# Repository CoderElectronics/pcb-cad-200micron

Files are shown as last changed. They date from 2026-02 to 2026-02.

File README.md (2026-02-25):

<div align="center">
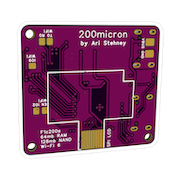
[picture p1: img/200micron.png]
200micron Setup Tool
  
  <h1>200micron SBC PCB/CAD</h1>
</div>

PCB/CAD for 200micron Linux Single-board computer. This is my attempt at designing a simple, low-cost and hand-assemble-able single-board computer for embedded robotics and UAV applications where a larger, more power-hungry system is not required. The board is completely single-sided and uses all SMD components >= 0402 size.

Best of all, it's open-source and comes with lots of resources and an SDK:
- [Custom Buildroot Tree w/ Cross SDK](https://github.com/CoderElectronics/buildroot-200micron)
- [Device Setup App](https://github.com/CoderElectronics/200micron-setup-tool)
- [Rust Cross-Compiled Project Template](https://github.com/CoderElectronics/rust-template-200micron)
- [Go Cross-Compiled Project Template](https://github.com/CoderElectronics/go-template-200micron)
- [Various modules, ports, and tools](https://github.com/CoderElectronics/)
- Bill of Materials (here)
- 4-layer 1.6mm PCB Gerber Files (here)
- Altium Designer Project (here)
- Case and Board Assembly CAD (here)

<br>
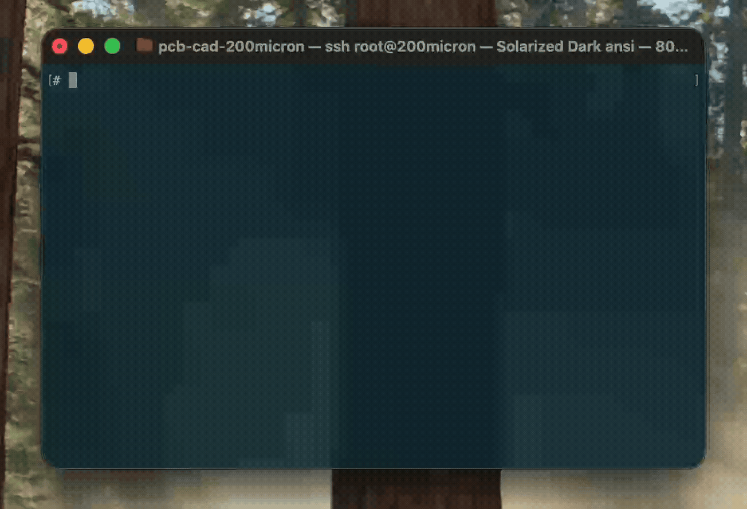
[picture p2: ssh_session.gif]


## Manufacturing

This board has been manufactured using the [OSHPark's](https://oshpark.com/) 4 Layer Prototype Service. Three bare PCBs costs roughly $16 USD. You can also order them through JLCPCB which will cost less per board, but more in shipping. Most components (except for CPU and PL2303GL serial bridge) are available through Digikey. (see the included BOM)

<div align="center">
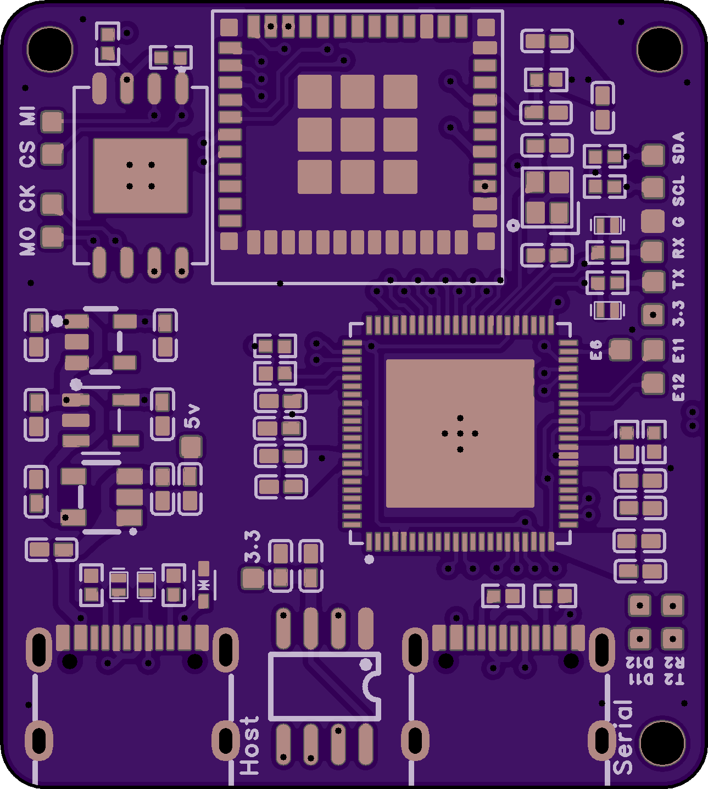
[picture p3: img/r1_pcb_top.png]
PCB Top
  
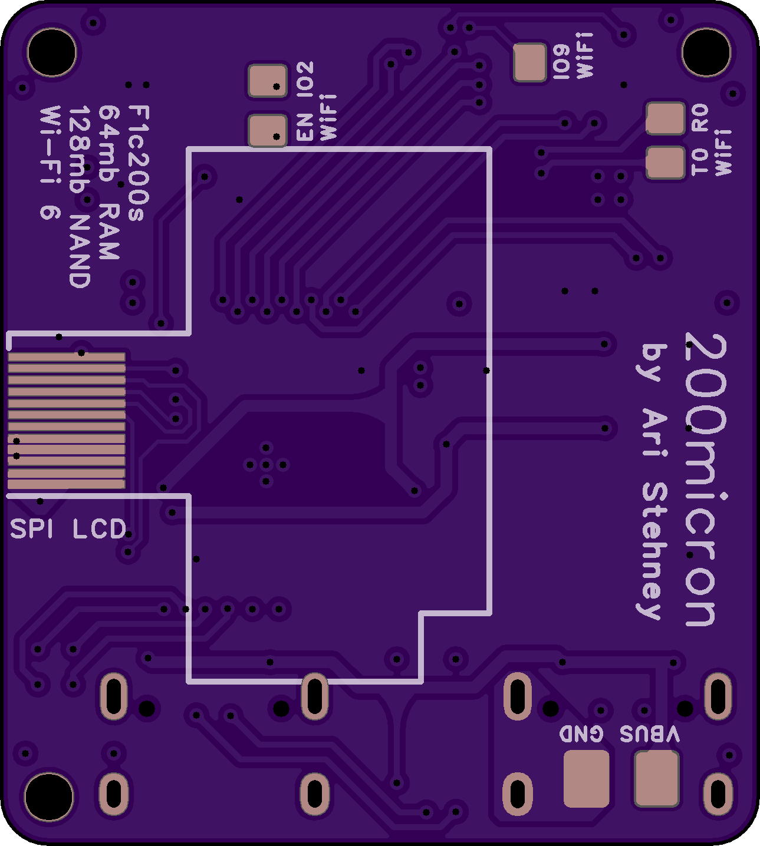
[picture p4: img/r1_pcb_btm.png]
PCB Bottom
  
</div>

## Assembly

The board is completely single-sided and can be assembled using a small USB-C hotplate and standard soldering equipment. The smallest passive component is 0402, and the CPU and ESP can be soldered by hand with a good bit of time. Ensure you have good quality solder paste and gel flux!

## Case

There is also CAD for a simple case that can be 3D printed out of PETG-CF or something similar that won't warp under heat. It requires the following hardware for each case:
- 3x M2x12mm screws
- 3x M2 nuts
- a small CPU heatsink

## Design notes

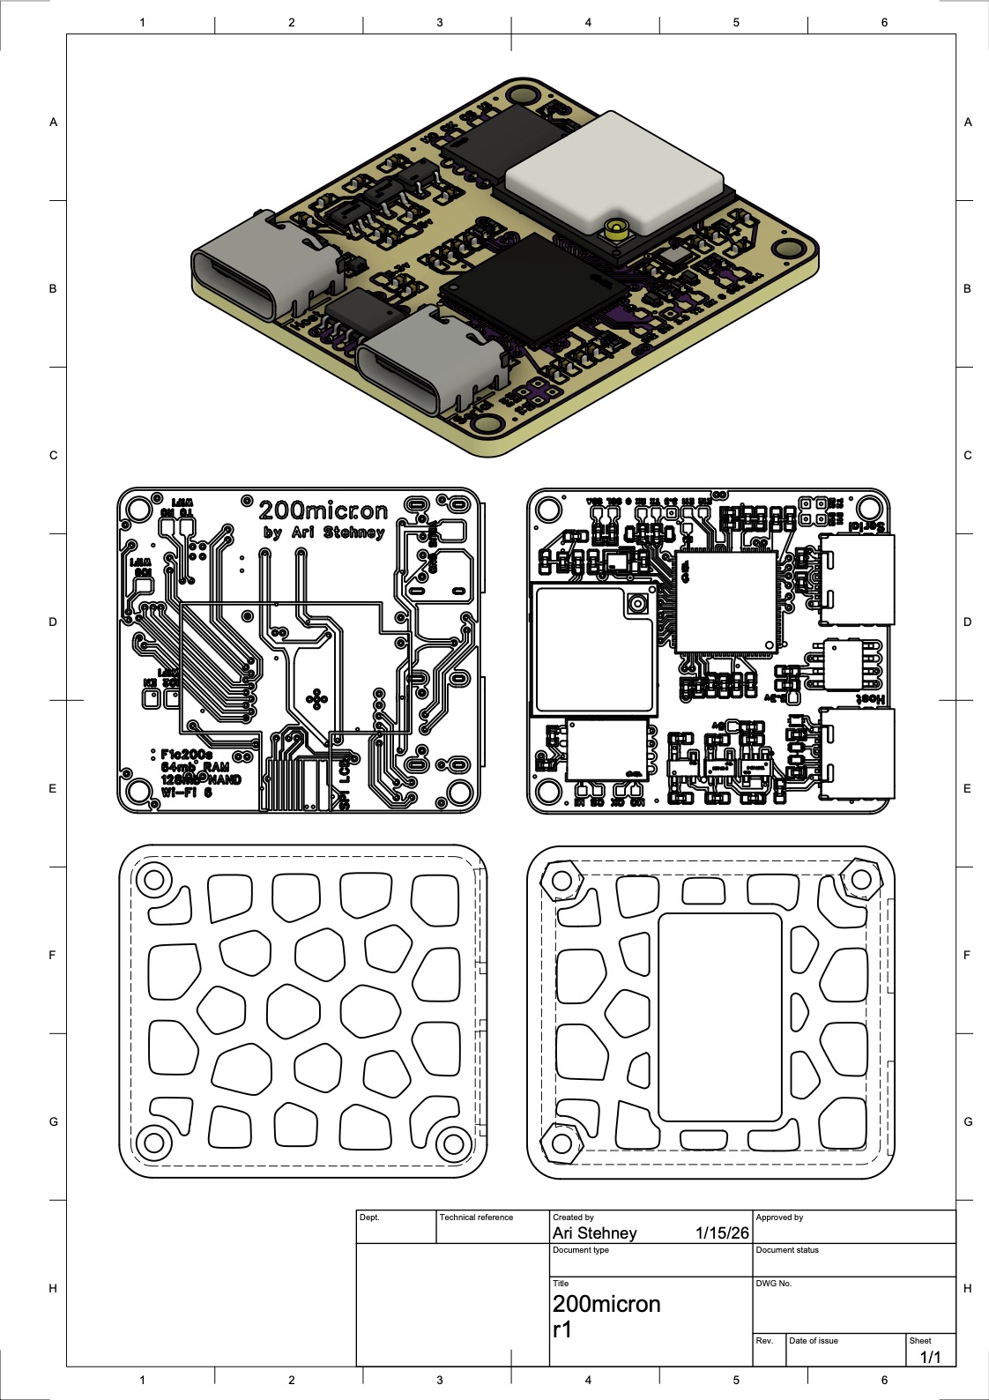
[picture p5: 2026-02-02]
drawings/200micron Drawing v4.jpg

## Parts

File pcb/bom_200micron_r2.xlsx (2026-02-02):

No. | Quantity | Comment | Designator | Footprint | Value | Manufacturer Part | Manufacturer | Supplier Part | Supplier
1 | 11 | 0.1uf | C15,C17,C19,C23,C24,C25,C26,C27,C28,C34,C41 | C0402 | 0.1uf
2 | 10 | 1uf | C16,C18,C20,C35,C36,C37,C38,C39,C40,C42 | C0402 | 1uf
3 | 2 | 18pf | C21,C22 | C0402 | 18pf
4 | 4 | LESD8D3.3CAT5G | D4,D5,D6,D7 | SOD-882_L1.0-W0.6-BI |  | LESD8D3.3CAT5G | LRC(乐山无线电) | C172409 | LCSC
5 | 2 | 200 | R21,R22 | R0402 | 200
6 | 4 | 5.1k | R23,R24,R32,R33 | R0402 | 5.1k
7 | 2 | 2.2k | R25,R26 | R0402 | 2.2k
8 | 6 | 10k | R27,R29,R35,R36,R37,R38 | R0402 | 10k
9 | 1 | F1C200S | U1 | QFN-88_L10.0-W10.0-P0.40-BL-EP6.75 |  | F1C200S | Allwinner(全志) | C2879851 | LCSC
10 | 1 | W25N01GVZEIG | U6 | WSON-8_L8.0-W6.10-P1.27-BL-EP |  | W25N01GVZEIG | Winbond(华邦) | C907680 | LCSC
11 | 1 | LESD5D5.0CT1G | U18 | SOD-523_L1.2-W0.8-LS1.6-BI |  | LESD5D5.0CT1G | KUU | C7433850 | LCSC
12 | 1 | XC6210B332MR | U19 | TSOT-23-5_L2.9-W1.6-P0.95-LS2.8-BR |  | XC6210B332MR | TOREX(特瑞仕) | C424705 | LCSC
13 | 1 | TLV71311PDBVR | U20 | SOT-23-5_L3.0-W1.7-P0.95-LS2.8-BL |  | TLV71311PDBVR | TI(德州仪器) | C205964 | LCSC
14 | 1 | TLV70225DBVR | U21 | SOT-23-5_L2.9-W1.6-P0.95-LS2.8-BR |  | TLV70225DBVR | TI(德州仪器) | C2877849 | LCSC
15 | 1 | 24MHz | U22 | CRYSTAL-SMD_4P-L2.0-W1.6-BL | 24MHz | ECS-240-12-37B-CKY-TR | ECS | C2450025 | LCSC
16 | 1 | HS20HS072RX | U23 | OLED-SMD_HS20HS072RX |  | HS20HS072RX | HS(汉昇) | C5329582 | LCSC
17 | 1 | PL2303GL | U28 | SOP-8_L4.9-W3.9-P1.27-LS6.0-BL |  | PL2303GL | PROLIFIC(旺玖) | C2905408 | LCSC
18 | 1 | ESP32-C6-MINI-1U-H4 | U31 | WIFIM-SMD_61P-L13.2-W12.5-P0.80 |  | ESP32-C6-MINI-1U-H4 | ESPRESSIF(乐鑫) | C20627095 | LCSC
19 | 2 | TYPE-C 16PIN 2MD(073) | USB2,USB3 | USB-C-SMD_TYPE-C-6PIN-2MD-073 |  | TYPE-C 16PIN 2MD(073) | SHOU HAN(首韩) | C2765186 | LCSC

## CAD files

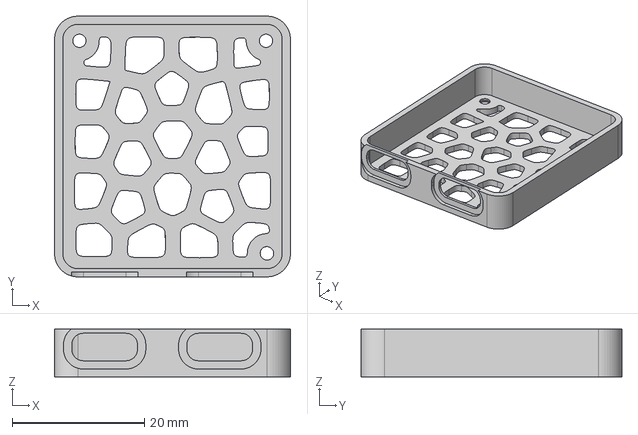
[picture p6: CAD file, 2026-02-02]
case/200micron Case Bottom.step
35.7 x 39.4 x 7.25 mm

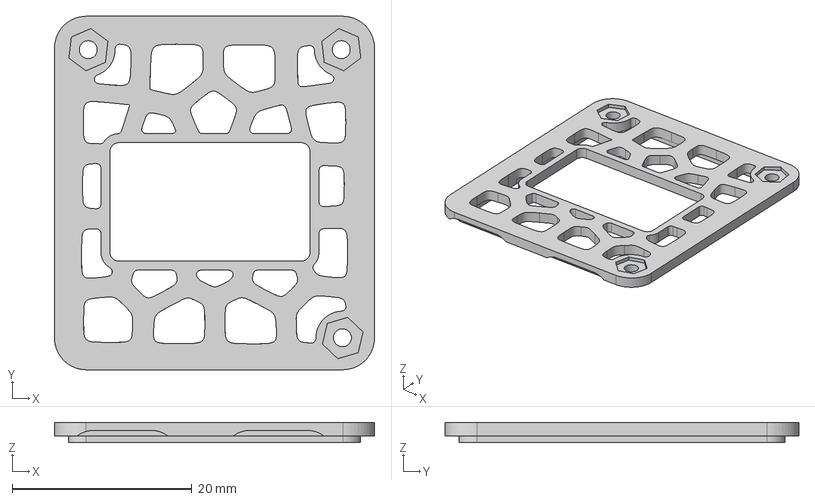
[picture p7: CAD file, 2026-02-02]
case/200micron Case Top.step
35.7 x 39.4 x 2.25 mm

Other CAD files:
case/200micron Case Bottom.stl
case/200micron Case Top.stl

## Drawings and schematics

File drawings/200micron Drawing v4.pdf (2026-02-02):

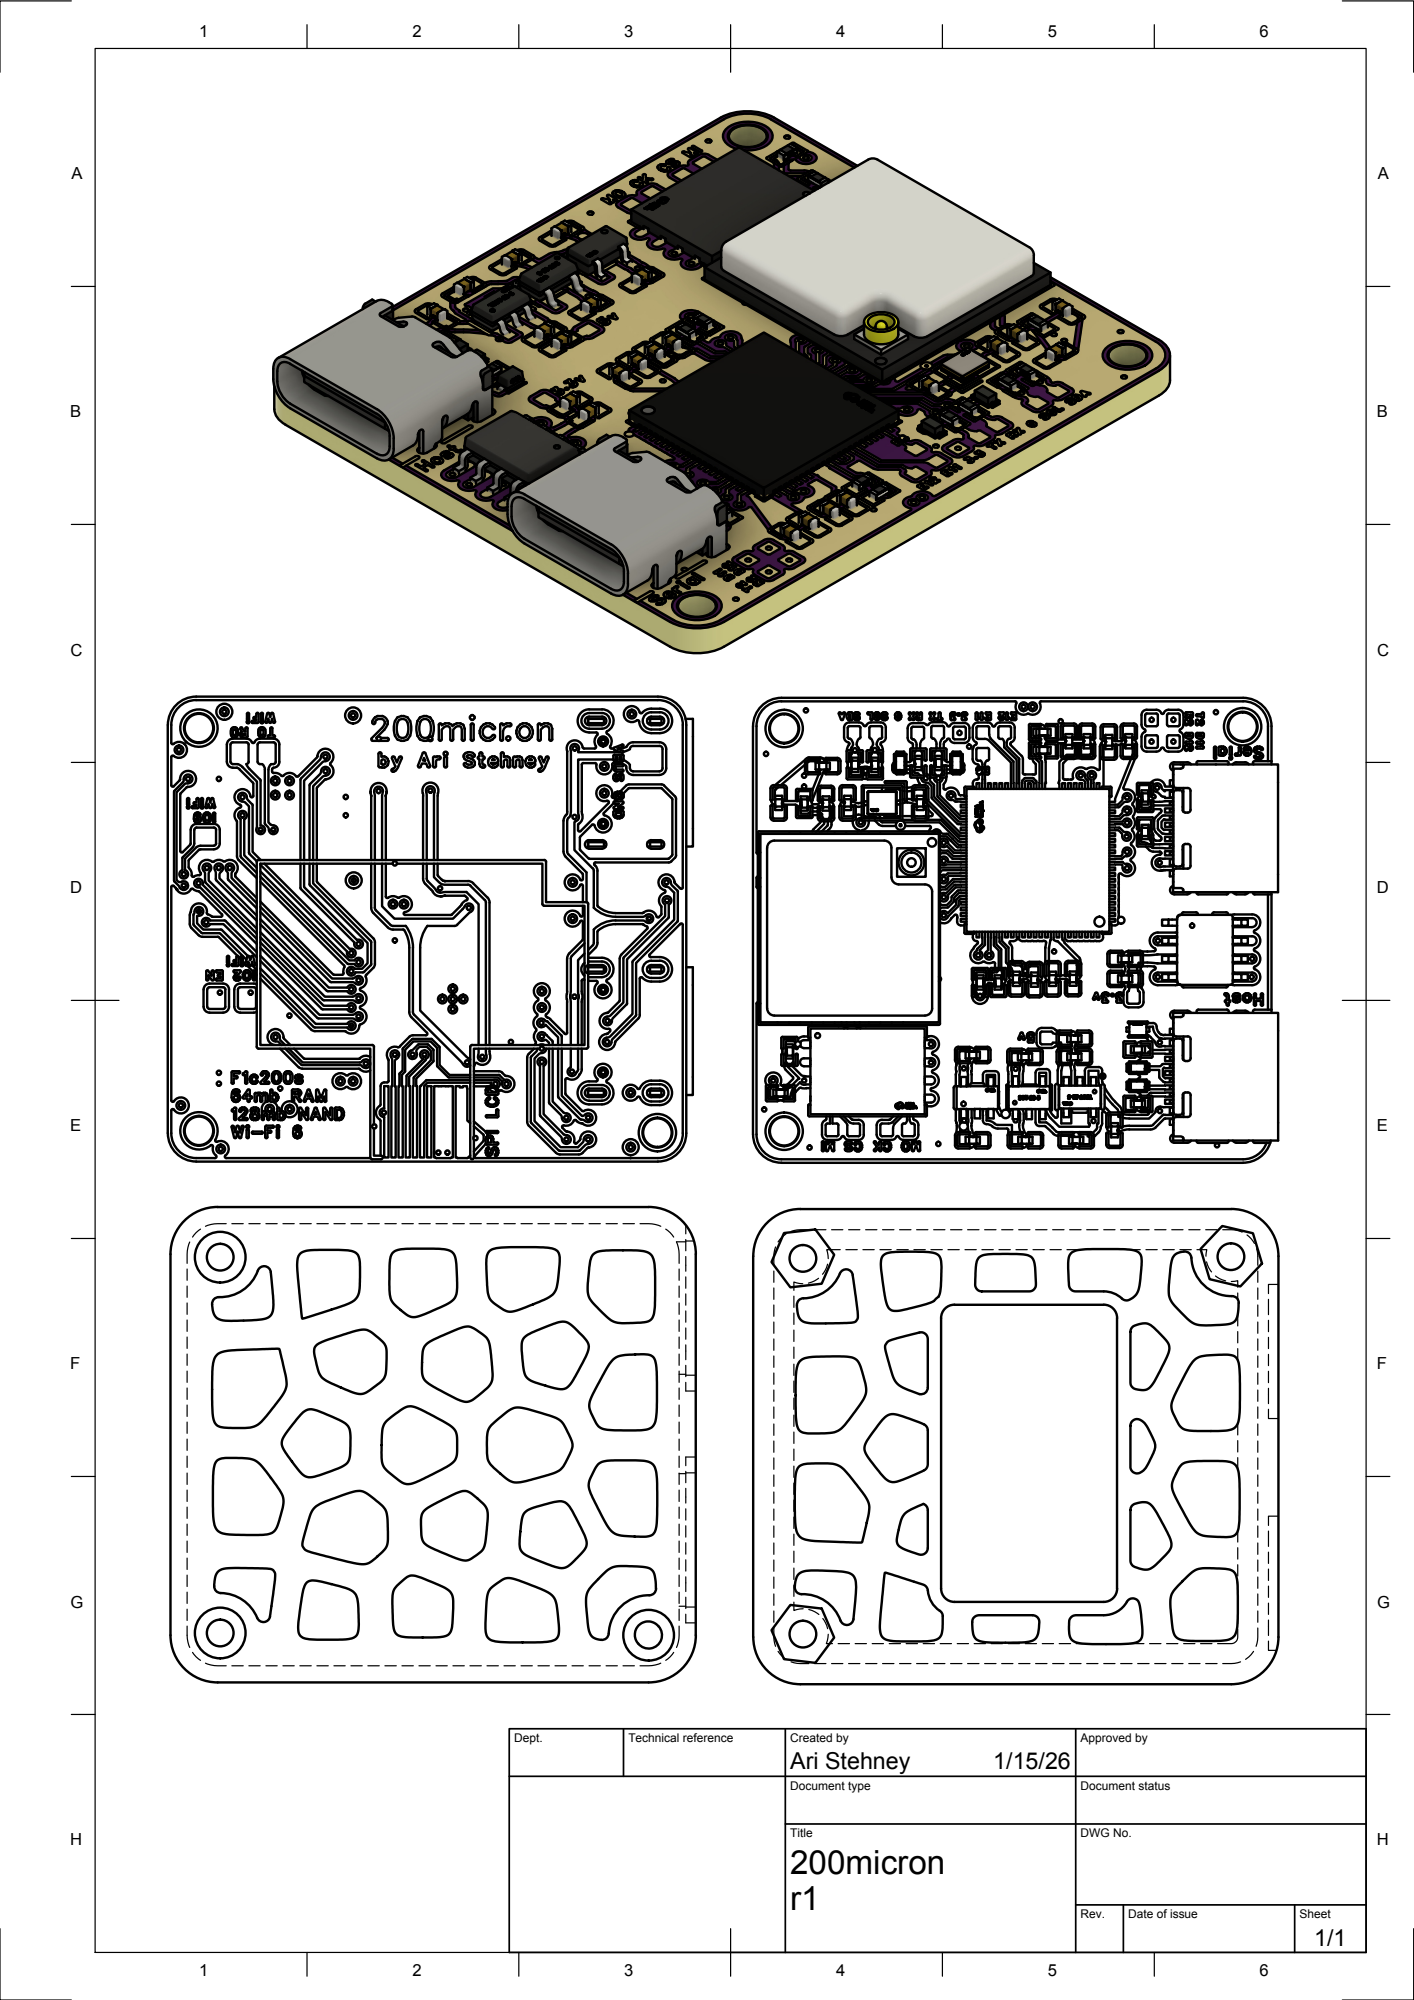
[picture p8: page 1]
Dept.; Technical reference; Created by; Approved by; Document type; Document status; Title; DWG No.; Rev.; Date of issue; Sheet; Ari Stehney

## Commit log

2026-02-02 big cad dump
    [1_Main.schdoc, 200micron Case Bottom.step, 200micron Case Bottom.stl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]
2026-02-02 new cad stuff
